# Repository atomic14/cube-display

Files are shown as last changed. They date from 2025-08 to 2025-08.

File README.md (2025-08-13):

# Cube Display

This is a work in progress project.

I'm currently testing the first set of PCBs. There will be updates as I find issues!

You can see some of the testing so far on my YouTube channel: [atomic14](https://www.youtube.com/@atomic14).

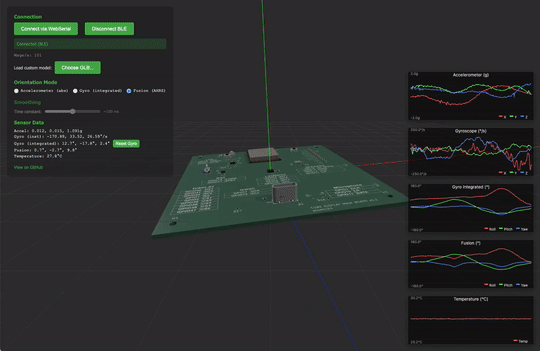
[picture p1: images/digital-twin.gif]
Here's the gyro and accelerometer working


The demo above is using the code from [here](https://github.com/atomic14/ESP32-LSM6DS3-Demo).

# Files

- display-board: 14 segment display board
- main-board: main board for the display-board
- main-board-tft: WIP - not complete.

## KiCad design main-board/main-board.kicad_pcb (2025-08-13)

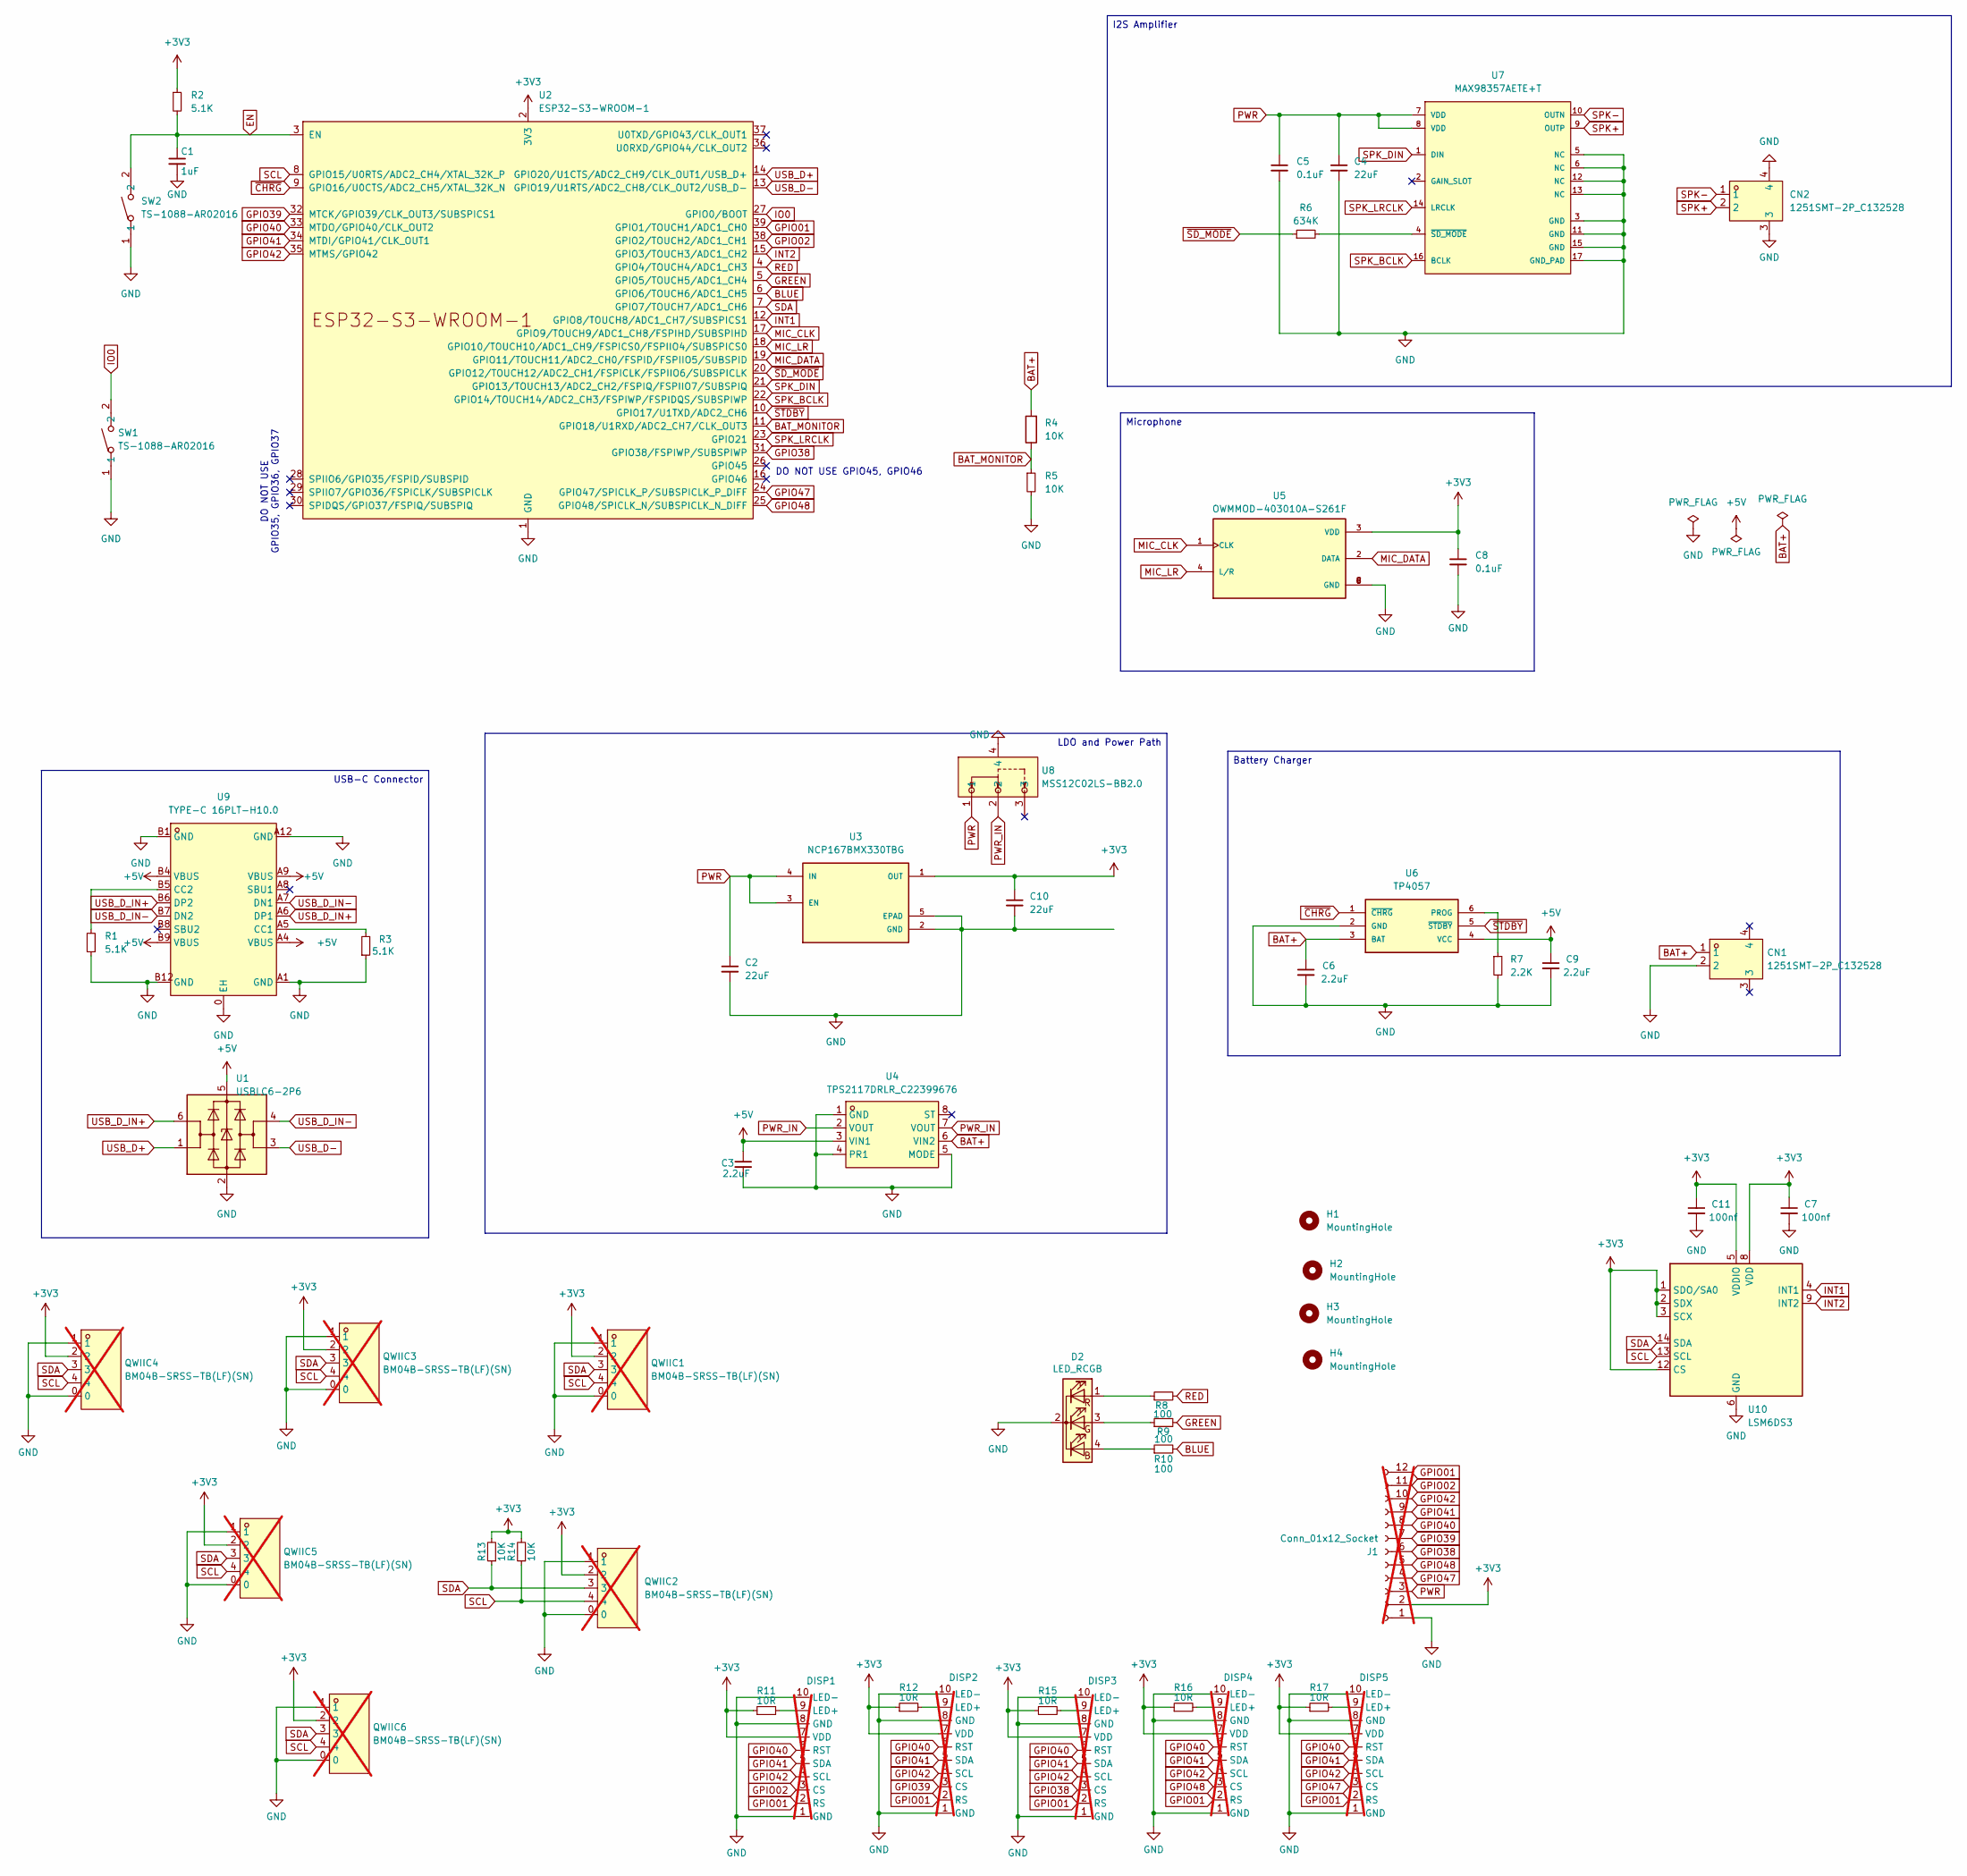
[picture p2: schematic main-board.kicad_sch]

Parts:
C1: 1uF; C_0402_1005Metric
C2, C4, C10: 22uF; C_0402_1005Metric
C3: 2.2uF; C_0402_1005Metric; Mfg Part # test
C5, C8: 0.1uF; C_0402_1005Metric
C6, C9: 2.2uF; C_0402_1005Metric
C7, C11: 100nf; C_0402_1005Metric
CN1, CN2: 1251SMT-2P_C132528; CONN-SMD_1251SMT-2P; LCSC Part C132528
D2: LED_RCGB; KAA-3528RGBS-11
DISP1, DISP2, DISP3, DISP4, DISP5: FPC_10_0.5; not fitted
H1, H2, H3, H4: MountingHole; MountingHole_2.2mm_M2
J1: Conn_01x12_Socket; PinSocket_1x12_P2.54mm_Vertical; not fitted
QWIIC1, QWIIC2, QWIIC3, QWIIC4, QWIIC5, QWIIC6: BM04B-SRSS-TB(LF)(SN); CONN-SMD_BM04B-SRSS-TB; LCSC Part C160390; not fitted
R1, R2, R3: 5.1K; R_0402_1005Metric
R4, R5, R13, R14: 10K; R_0402_1005Metric
R6: 634K; R_0402_1005Metric
R7: 2.2K; R_0402_1005Metric
R8, R9, R10: 100; R_0402_1005Metric
R11, R12, R15, R16, R17: 10R; R_0402_1005Metric
SW1, SW2: TS-1088-AR02016; SW-SMD_L3.9-W3.0-P4.45; LCSC Part C720477
U1: USBLC6-2P6; SOT-666
U2: ESP32-S3-WROOM-1
U3: NCP167BMX330TBG; VREG_NCP167BMX330TBG; PARTREV 5
U4: TPS2117DRLR_C22399676; SOT-583-8; LCSC Part C22399676
U5: OWMMOD-403010A-S261F; MIC_OWMMOD-403010A-S261F; PARTREV 00; DigiKey_Part_Number 3949-OWMMOD-403010A-S261F-ND
U6: TP4057; SOT-23-6
U7: MAX98357AETE+T; Maxim_Electronics-21-0896-0-0-0; mouser part number 700-MAX98357AETE+T; digikey description Amplifier IC 2-Channel (Stereo) Class D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
U8: MSS12C02LS-BB2.0; SW-SMD_MSS12C02LS-HB2.0-1; LCSC Part C3008585
U9: TYPE-C 16PLT-H10.0; TYPE-C-SMD_USB4120-03-C; LCSC Part C3151749
U10: LSM6DS3; LGA-14_3x2.5mm_P0.5mm_LayoutBorder3x4y

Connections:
+3V3: C7.1, C8.1, C10.1, C11.1, DISP1.7 (VDD), DISP2.7 (VDD), DISP3.7 (VDD), DISP4.7 (VDD), DISP5.7 (VDD), J1.2, QWIIC1.2, QWIIC2.2, QWIIC3.2, QWIIC4.2, QWIIC5.2, QWIIC6.2, R2.1, R11.1, R12.1, R13.2, R14.2, R15.1, R16.1, R17.1, U2.2 (3V3), U3.1 (OUT), U5.3 (VDD), U10.1 (SDO/SA0), U10.2 (SDX), U10.3 (SCX), U10.5 (VDDIO), U10.8 (VDD), U10.12 (CS)
+5V: C3.1, C9.1, U1.5 (VBUS), U4.3 (VIN1), U6.4 (VCC), U9.A4 (VBUS), U9.A9 (VBUS), U9.B4 (VBUS), U9.B9 (VBUS)
BAT+: C6.1, CN1.1, R4.2, U4.6 (VIN2), U6.3 (BAT)
BAT_MONITOR: R4.1, R5.1, U2.11 (GPIO18/U1RXD/ADC2_CH7/CLK_OUT3)
BLUE: R10.2, U2.6 (GPIO6/TOUCH6/ADC1_CH5)
EN: C1.1, R2.2, SW2.2, U2.3 (EN)
GND: C1.2, C2.2, C3.2, C4.2, C5.2, C6.2, C7.2, C8.2, C9.2, C10.2, C11.2, CN1.2, CN2.3, CN2.4, D2.2 (K), DISP1.1 (GND), DISP1.8 (GND), DISP1.10 (LED-), DISP2.1 (GND), DISP2.8 (GND), DISP2.10 (LED-), DISP3.1 (GND), DISP3.8 (GND), DISP3.10 (LED-), DISP4.1 (GND), DISP4.8 (GND), DISP4.10 (LED-), DISP5.1 (GND), DISP5.8 (GND), DISP5.10 (LED-), J1.1, QWIIC1.0, QWIIC1.1, QWIIC2.0, QWIIC2.1, QWIIC3.0, QWIIC3.1, QWIIC4.0, QWIIC4.1, QWIIC5.0, QWIIC5.1, QWIIC6.0, QWIIC6.1, R1.1, R3.1, R5.2, R7.2, SW1.1, SW2.1, U1.2 (GND), U2.1 (GND), U2.40 (GND), U2.41 (GND), U3.2 (GND), U3.5 (EPAD), U4.1 (GND), U4.4 (PR1), U4.5 (MODE), U5.5 (GND), U5.6 (GND), U5.7 (GND), U5.8 (GND), U6.2 (GND), U7.3 (GND), U7.5 (NC), U7.6 (NC), U7.11 (GND), U7.12 (NC), U7.13 (NC), U7.15 (GND), U7.17 (GND_PAD), U8.4, U9.0 (EH), U9.A1 (GND), U9.A12 (GND), U9.B1 (GND), U9.B12 (GND), U10.6 (GND), U10.7 (GND)
GPIO01: DISP1.2 (RS), DISP2.2 (RS), DISP3.2 (RS), DISP4.2 (RS), DISP5.2 (RS), J1.12, U2.39 (GPIO1/TOUCH1/ADC1_CH0)
GPIO02: DISP1.3 (CS), J1.11, U2.38 (GPIO2/TOUCH2/ADC1_CH1)
GPIO38: DISP3.3 (CS), J1.6, U2.31 (GPIO38/FSPIWP/SUBSPIWP)
GPIO39: DISP2.3 (CS), J1.7, U2.32 (MTCK/GPIO39/CLK_OUT3/SUBSPICS1)
GPIO40: DISP1.6 (RST), DISP2.6 (RST), DISP3.6 (RST), DISP4.6 (RST), DISP5.6 (RST), J1.8, U2.33 (MTDO/GPIO40/CLK_OUT2)
GPIO41: DISP1.5 (SDA), DISP2.5 (SDA), DISP3.5 (SDA), DISP4.5 (SDA), DISP5.5 (SDA), J1.9, U2.34 (MTDI/GPIO41/CLK_OUT1)
GPIO42: DISP1.4 (SCL), DISP2.4 (SCL), DISP3.4 (SCL), DISP4.4 (SCL), DISP5.4 (SCL), J1.10, U2.35 (MTMS/GPIO42)
GPIO47: DISP5.3 (CS), J1.4, U2.24 (GPIO47/SPICLK_P/SUBSPICLK_P_DIFF)
GPIO48: DISP4.3 (CS), J1.5, U2.25 (GPIO48/SPICLK_N/SUBSPICLK_N_DIFF)
GREEN: R9.2, U2.5 (GPIO5/TOUCH5/ADC1_CH4)
INT1: U2.12 (GPIO8/TOUCH8/ADC1_CH7/SUBSPICS1), U10.4 (INT1)
INT2: U2.15 (GPIO3/TOUCH3/ADC1_CH2), U10.9 (INT2)
IO0: SW1.2, U2.27 (GPIO0/BOOT)
MIC_CLK: U2.17 (GPIO9/TOUCH9/ADC1_CH8/FSPIHD/SUBSPIHD), U5.1 (CLK)
MIC_DATA: U2.19 (GPIO11/TOUCH11/ADC2_CH0/FSPID/FSPIIO5/S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), U5.2 (DATA)
MIC_LR: U2.18 (GPIO10/TOUCH10/ADC1_CH9/FSPICS0/FSPIIO4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), U5.4 (L/R)
unnamed: D2.4 (BA), R10.1
unnamed: D2.3 (GA), R9.1
unnamed: D2.1 (RA), R8.1
unnamed: DISP1.9 (LED+), R11.2
unnamed: DISP2.9 (LED+), R12.2
unnamed: DISP3.9 (LED+), R15.2
unnamed: DISP4.9 (LED+), R16.2
unnamed: DISP5.9 (LED+), R17.2
unnamed: R7.1, U6.6 (PROG)
unnamed: R6.2, U7.4 (~SD_MODE)
unnamed: R3.2, U9.A5 (CC1)
unnamed: R1.2, U9.B5 (CC2)
PWR: C2.1, C4.1, C5.1, J1.3, U3.3 (EN), U3.4 (IN), U7.7 (VDD), U7.8 (VDD), U8.1
PWR_IN: U4.2 (VOUT), U4.7 (VOUT), U8.2
RED: R8.2, U2.4 (GPIO4/TOUCH4/ADC1_CH3)
SCL: QWIIC1.4, QWIIC2.4, QWIIC3.4, QWIIC4.4, QWIIC5.4, QWIIC6.4, R14.1, U2.8 (GPIO15/U0RTS/ADC2_CH4/XTAL_32K_P), U10.13 (SCL)
SDA: QWIIC1.3, QWIIC2.3, QWIIC3.3, QWIIC4.3, QWIIC5.3, QWIIC6.3, R13.1, U2.7 (GPIO7/TOUCH7/ADC1_CH6), U10.14 (SDA)
SPK+: CN2.2, U7.9 (OUTP)
SPK-: CN2.1, U7.10 (OUTN)
SPK_BCLK: U2.22 (GPIO14/TOUCH14/ADC2_CH3/FSPIWP/FSPIDQS/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), U7.16 (BCLK)
SPK_DIN: U2.21 (GPIO13/TOUCH13/ADC2_CH2/FSPIQ/FSPIIO7/S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), U7.1 (DIN)
SPK_LRCLK: U2.23 (GPIO21), U7.14 (LRCLK)
USB_D+: U1.1 (I/O1), U2.14 (GPIO20/U1CTS/ADC2_CH9/CLK_OUT1/USB_D+)
USB_D-: U1.3 (I/O2), U2.13 (GPIO19/U1RTS/ADC2_CH8/CLK_OUT2/USB_D-)
USB_D_IN+: U1.6 (I/O1), U9.A6 (DP1), U9.B6 (DP2)
USB_D_IN-: U1.4 (I/O2), U9.A7 (DN1), U9.B7 (DN2)
~CHRG: U2.9 (GPIO16/U0CTS/ADC2_CH5/XTAL_32K_N), U6.1 (~CHRG)
~SD_MODE: R6.1, U2.20 (GPIO12/TOUCH12/ADC2_CH1/FSPICLK/FSPIIO6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)
~STDBY: U2.10 (GPIO17/U1TXD/ADC2_CH6), U6.5 (~STDBY)

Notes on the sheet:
DO NOT USE GPIO35, GPIO36, GPIO37
DO NOT USE GPIO45, GPIO46
Battery Charger
USB-C Connector
I2S Amplifier
Microphone
LDO and Power Path

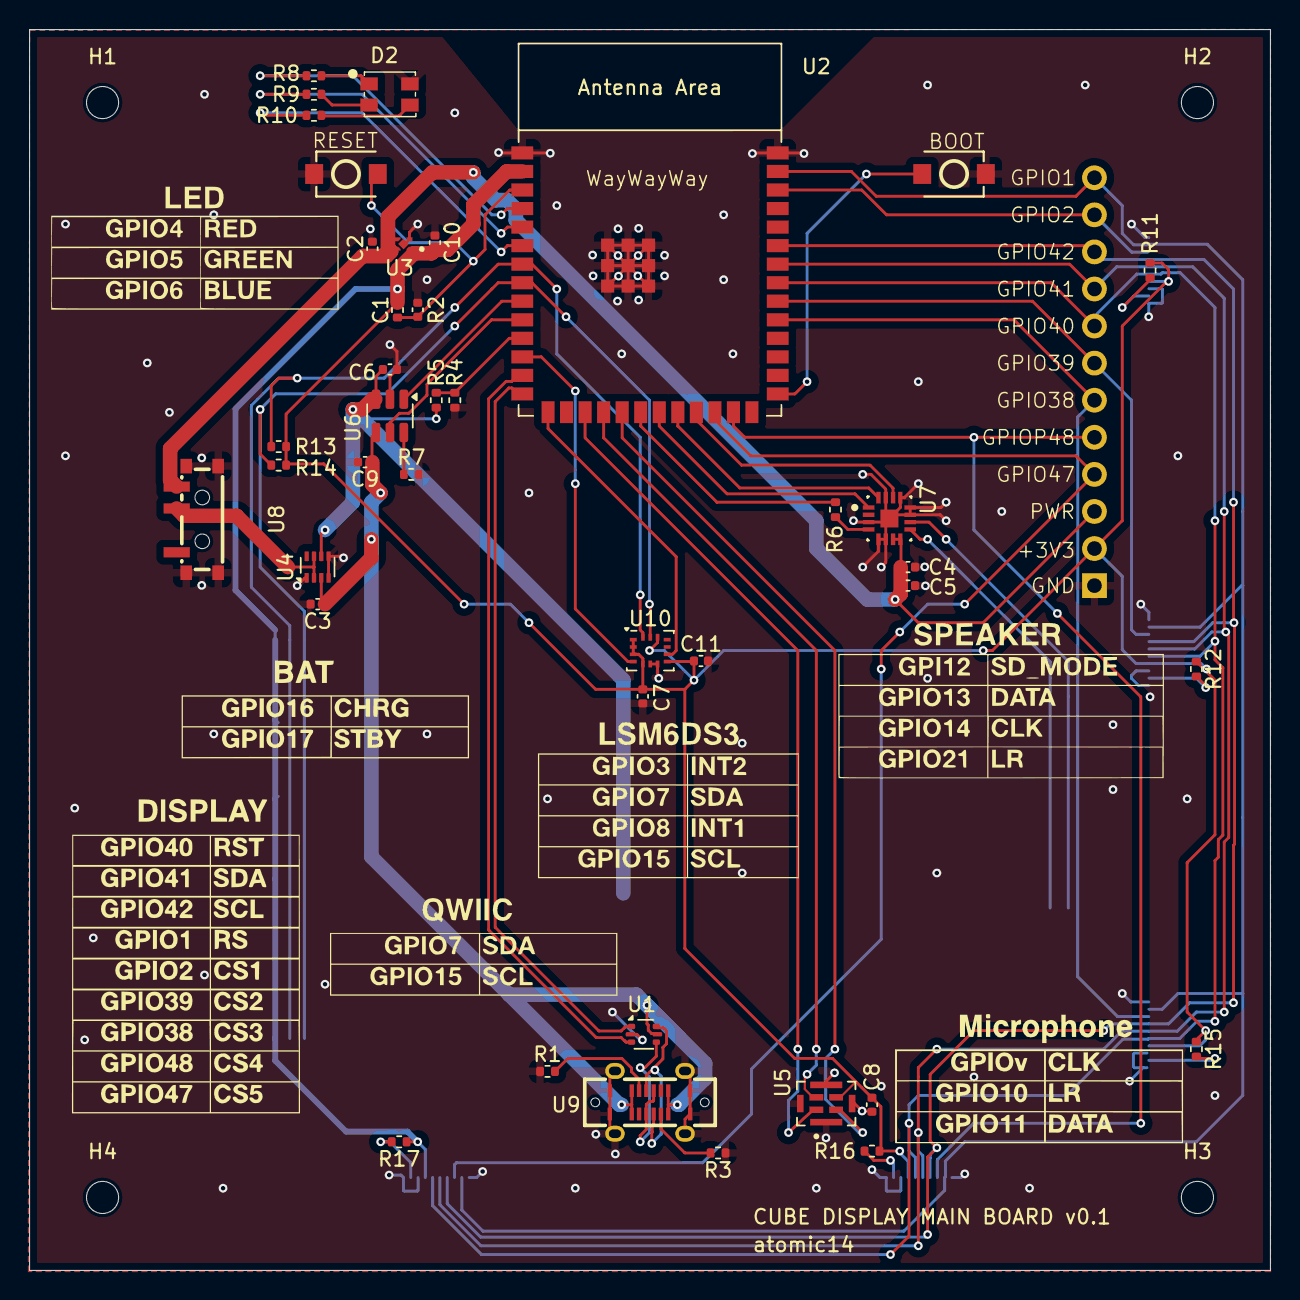
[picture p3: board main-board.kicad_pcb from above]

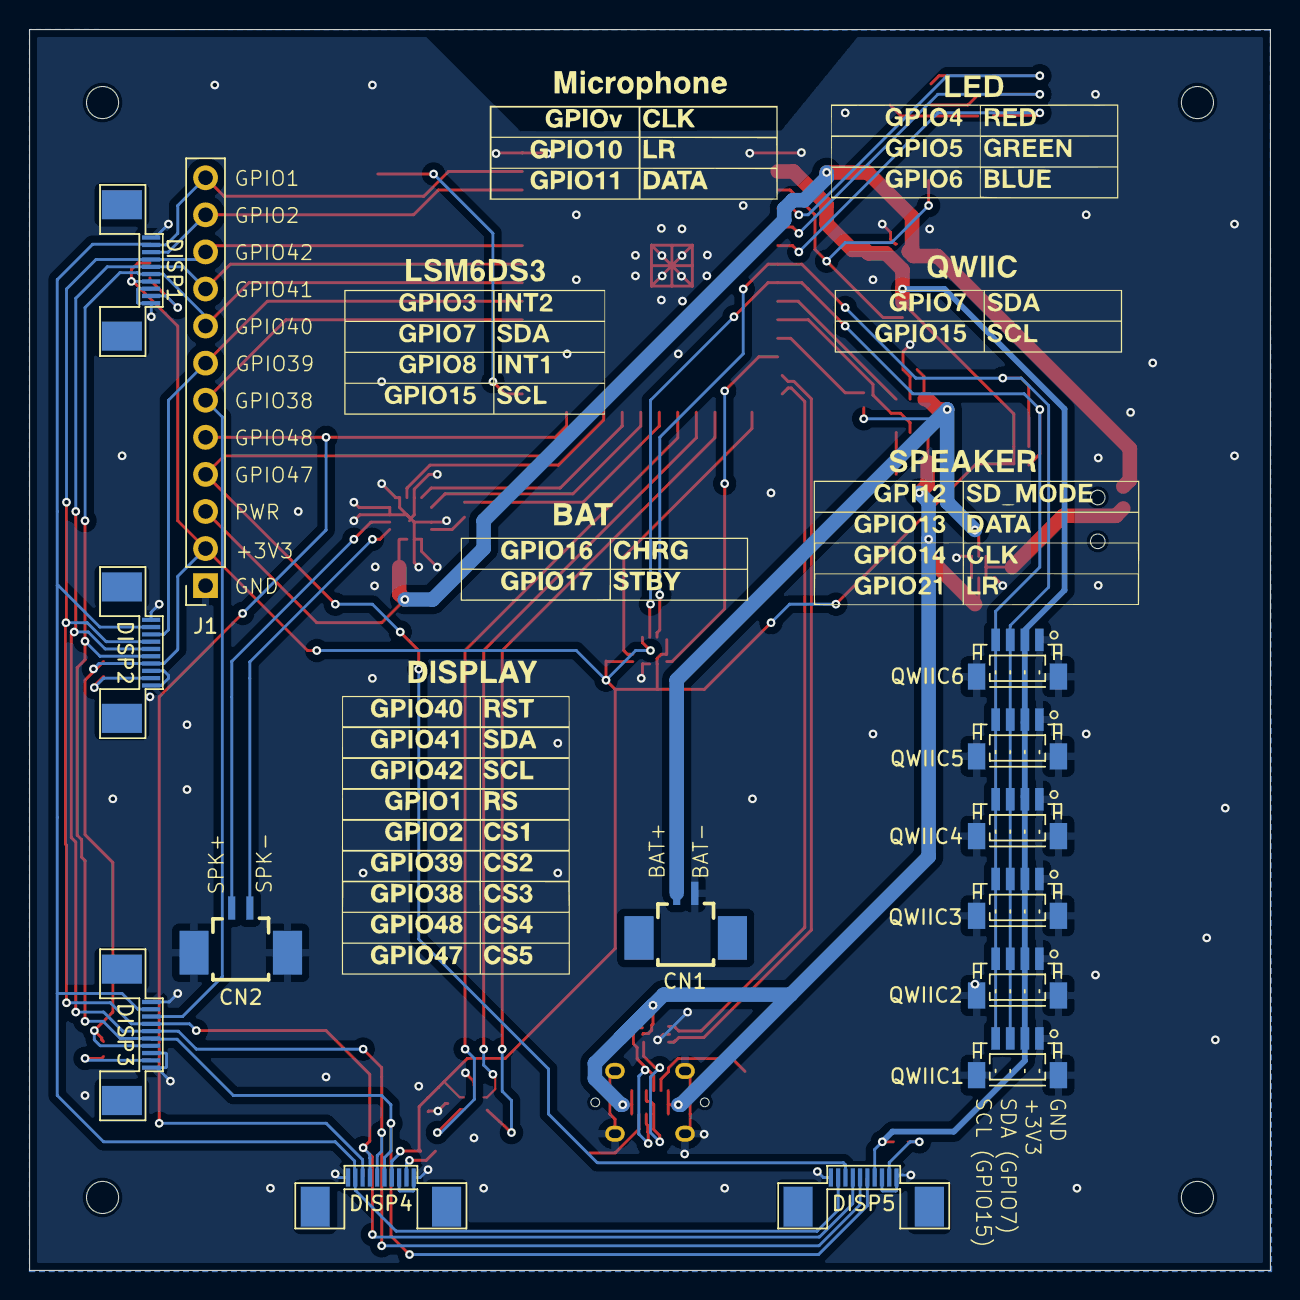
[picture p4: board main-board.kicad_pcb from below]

Board: 2 copper layers, 85.0 x 85.0 mm, 59 parts (14 on the bottom side), 52 nets.

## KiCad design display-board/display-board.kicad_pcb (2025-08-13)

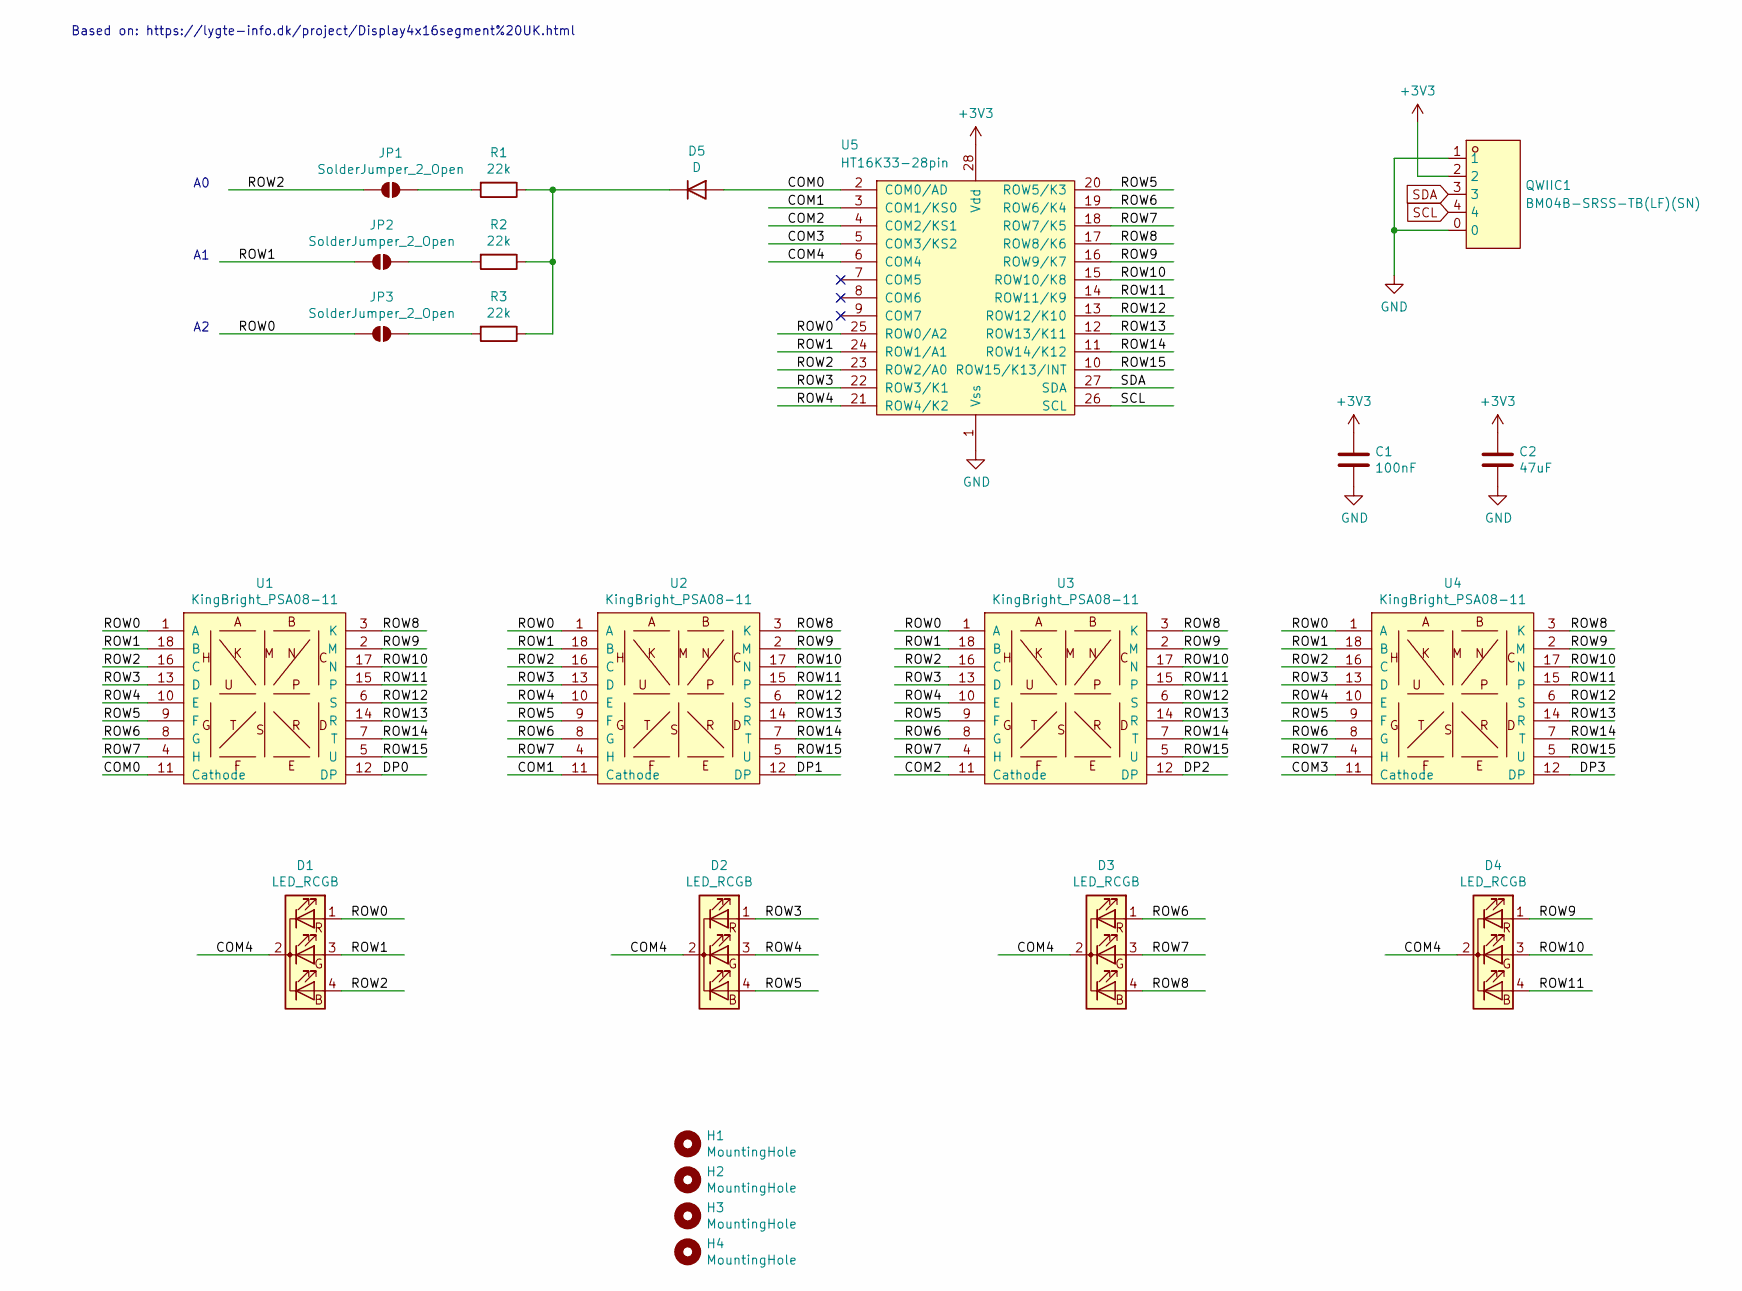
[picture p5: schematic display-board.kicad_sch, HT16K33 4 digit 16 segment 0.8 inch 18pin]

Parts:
C1: 100nF; C_0603_1608Metric
C2: 47uF; C_0603_1608Metric
D1, D2, D3, D4: LED_RCGB; KAA-3528RGBS-11
D5: D; D_SOD-323
H1, H2, H3, H4: MountingHole; MountingHole_2.2mm_M2
JP1, JP2, JP3: SolderJumper_2_Open; SolderJumper-2_P1.3mm_Open_RoundedPad1.0x1.5mm
QWIIC1: BM04B-SRSS-TB(LF)(SN); CONN-SMD_BM04B-SRSS-TB; LCSC Part C160390
R1, R2, R3: 22k; R_0603_1608Metric
U1, U2, U3, U4: KingBright_PSA08-11; DIP-18_600_ELL
U5: HT16K33-28pin; SOIC-28W_7.5x18.7mm_P1.27mm

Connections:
+3V3: C1.1, C2.1, QWIIC1.2, U5.28 (Vdd)
/COM0: D5.2 (A), U1.11 (Cathode), U5.2 (COM0/AD)
/COM1: U2.11 (Cathode), U5.3 (COM1/KS0)
/COM2: U3.11 (Cathode), U5.4 (COM2/KS1)
/COM3: U4.11 (Cathode), U5.5 (COM3/KS2)
/COM4: D1.2 (K), D2.2 (K), D3.2 (K), D4.2 (K), U5.6 (COM4)
/DP0: U1.12 (DP)
/DP1: U2.12 (DP)
/DP2: U3.12 (DP)
/DP3: U4.12 (DP)
/ROW0: D1.1 (RA), JP3.1 (A), U1.1 (A), U2.1 (A), U3.1 (A), U4.1 (A), U5.25 (ROW0/A2)
/ROW1: D1.3 (GA), JP2.1 (A), U1.18 (B), U2.18 (B), U3.18 (B), U4.18 (B), U5.24 (ROW1/A1)
/ROW2: D1.4 (BA), JP1.1 (A), U1.16 (C), U2.16 (C), U3.16 (C), U4.16 (C), U5.23 (ROW2/A0)
/ROW3: D2.1 (RA), U1.13 (D), U2.13 (D), U3.13 (D), U4.13 (D), U5.22 (ROW3/K1)
/ROW4: D2.3 (GA), U1.10 (E), U2.10 (E), U3.10 (E), U4.10 (E), U5.21 (ROW4/K2)
/ROW5: D2.4 (BA), U1.9 (F), U2.9 (F), U3.9 (F), U4.9 (F), U5.20 (ROW5/K3)
/ROW6: D3.1 (RA), U1.8 (G), U2.8 (G), U3.8 (G), U4.8 (G), U5.19 (ROW6/K4)
/ROW7: D3.3 (GA), U1.4 (H), U2.4 (H), U3.4 (H), U4.4 (H), U5.18 (ROW7/K5)
/ROW8: D3.4 (BA), U1.3 (K), U2.3 (K), U3.3 (K), U4.3 (K), U5.17 (ROW8/K6)
/ROW9: D4.1 (RA), U1.2 (M), U2.2 (M), U3.2 (M), U4.2 (M), U5.16 (ROW9/K7)
/ROW10: D4.3 (GA), U1.17 (N), U2.17 (N), U3.17 (N), U4.17 (N), U5.15 (ROW10/K8)
/ROW11: D4.4 (BA), U1.15, U2.15, U3.15, U4.15, U5.14 (ROW11/K9)
/ROW12: U1.6 (S), U2.6 (S), U3.6 (S), U4.6 (S), U5.13 (ROW12/K10)
/ROW13: U1.14 (R), U2.14 (R), U3.14 (R), U4.14 (R), U5.12 (ROW13/K11)
/ROW14: U1.7 (T), U2.7 (T), U3.7 (T), U4.7 (T), U5.11 (ROW14/K12)
/ROW15: U1.5 (U), U2.5 (U), U3.5 (U), U4.5 (U), U5.10 (ROW15/K13/INT)
GND: C1.2, C2.2, QWIIC1.0, QWIIC1.1, U5.1 (Vss)
unnamed: D5.1 (K), R1.1, R2.1, R3.1
unnamed: JP1.2 (B), R1.2
unnamed: JP2.2 (B), R2.2
unnamed: JP3.2 (B), R3.2
SCL: QWIIC1.4, U5.26 (SCL)
SDA: QWIIC1.3, U5.27 (SDA)

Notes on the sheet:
Based on: https://lygte-info.dk/project/Display4x16segment%20UK.html

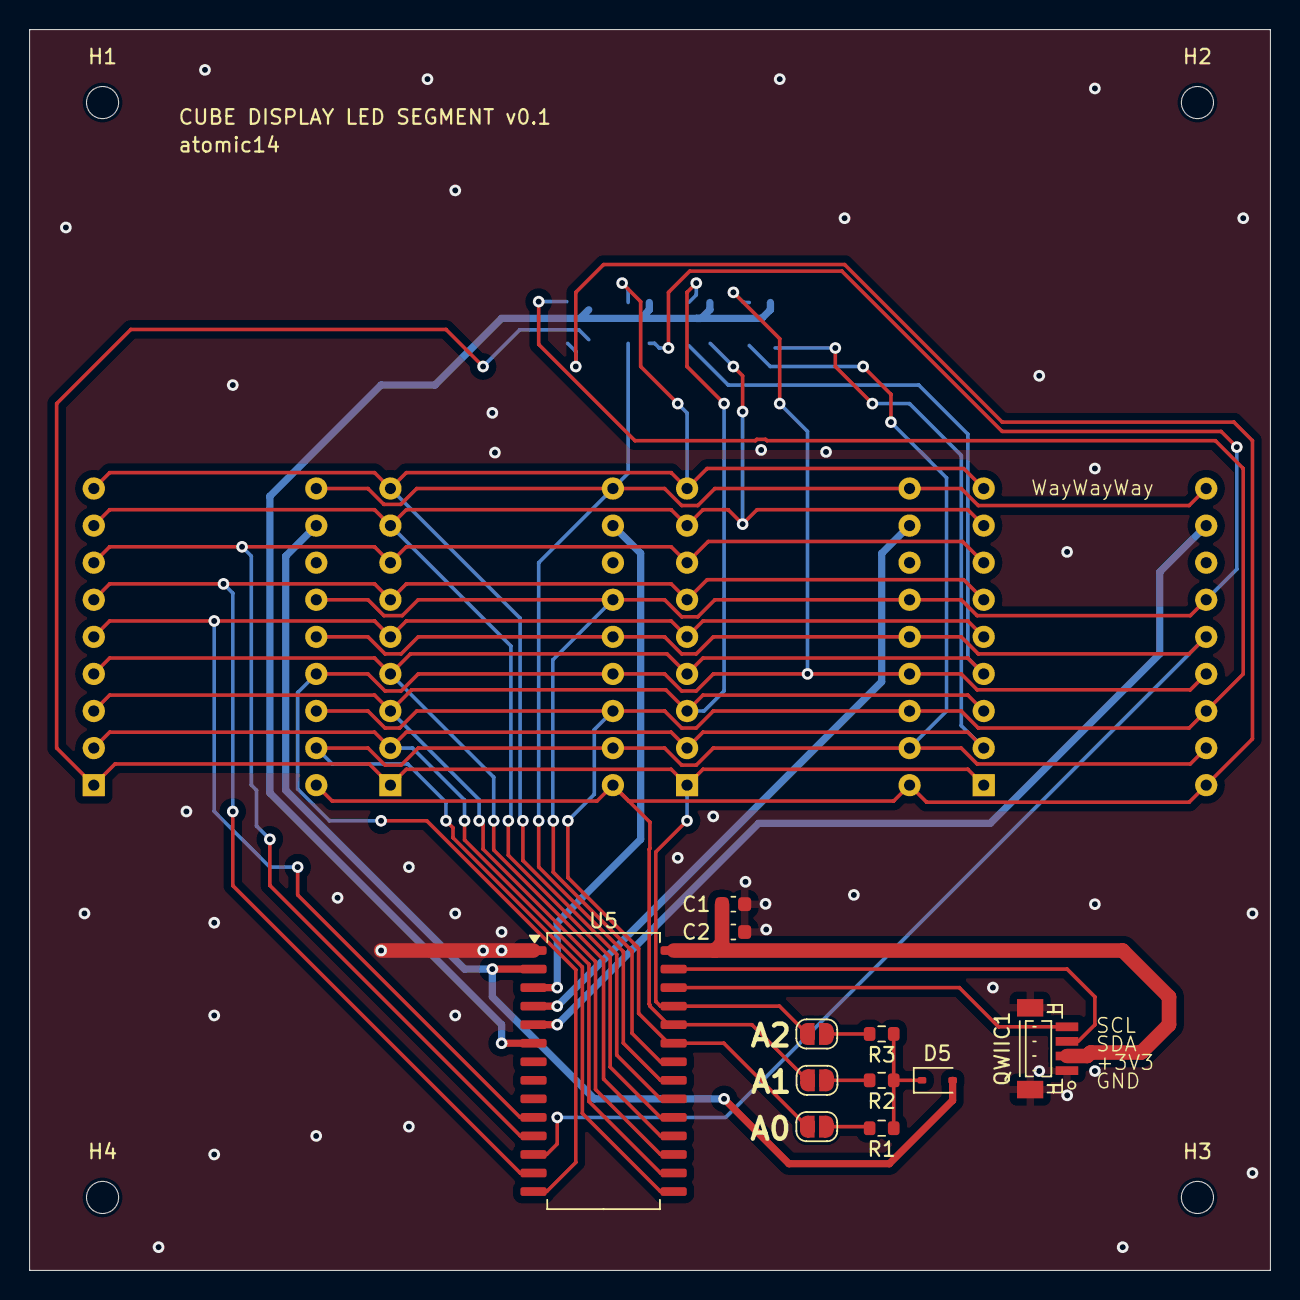
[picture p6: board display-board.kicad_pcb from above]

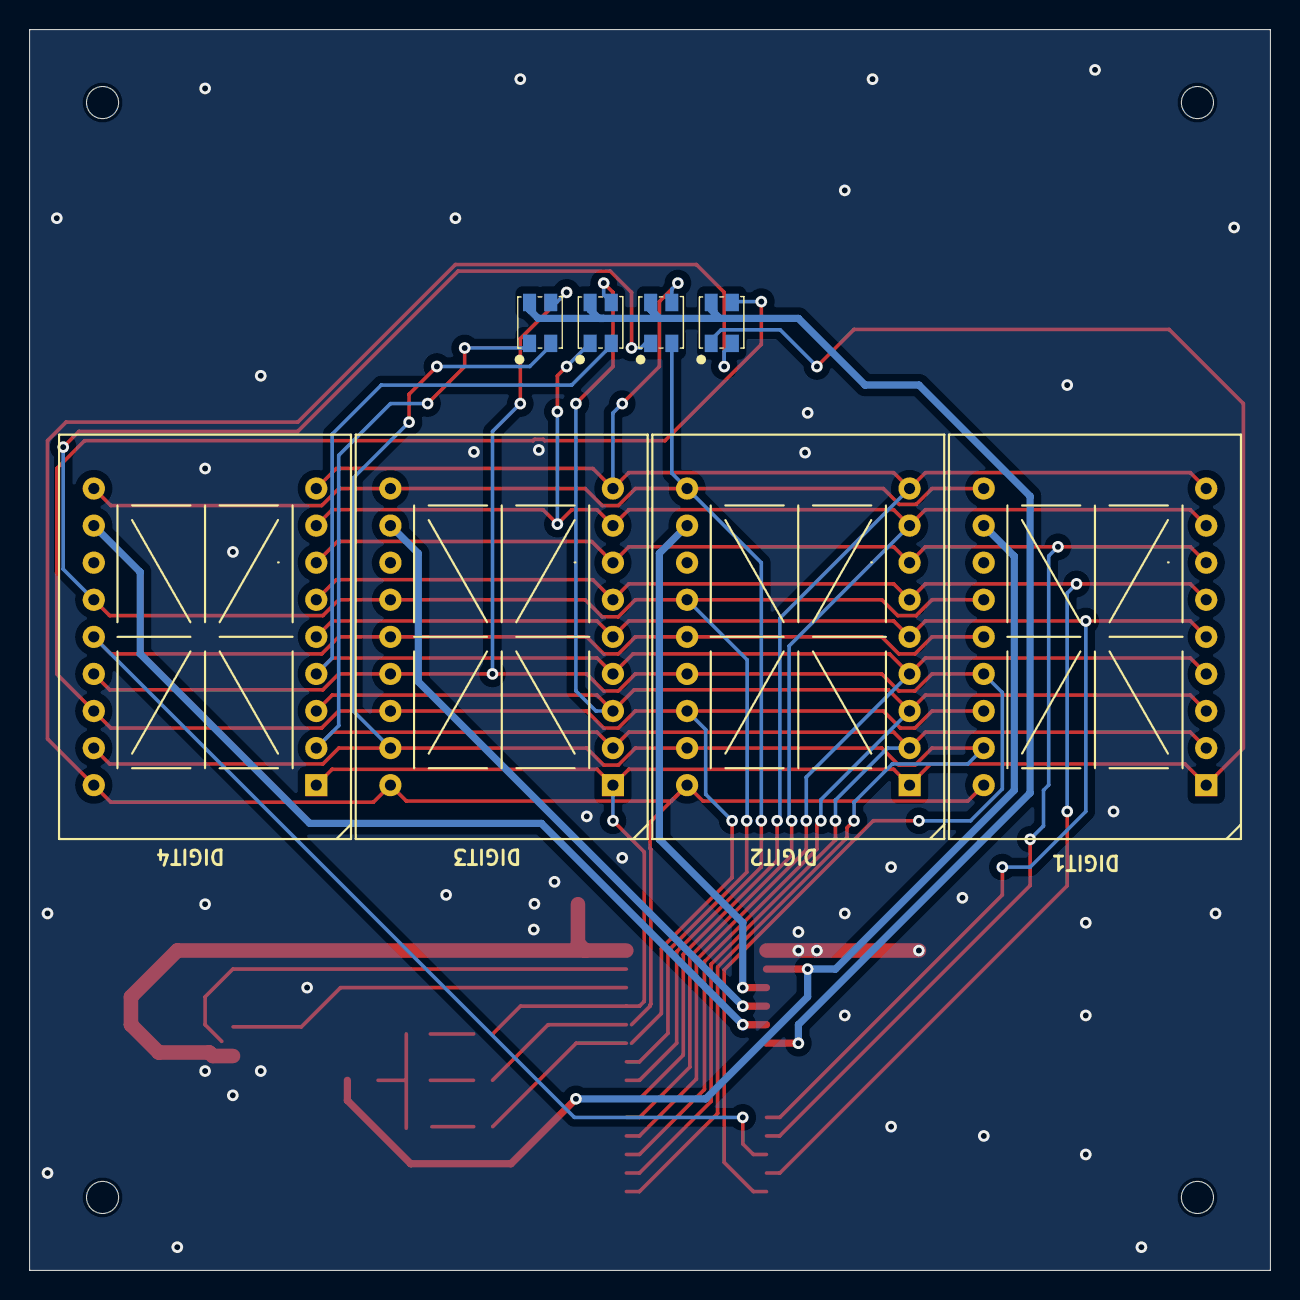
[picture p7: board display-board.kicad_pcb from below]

Board: 2 copper layers, 85.0 x 85.0 mm, 23 parts (8 on the bottom side), 29 nets.
